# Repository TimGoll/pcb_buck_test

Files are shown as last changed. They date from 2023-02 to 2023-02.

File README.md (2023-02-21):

# Buck Test PCB

To get an understanding of different buck ICs and their drawbacks and benefits I designed this PCB. While all of them worked, some performed better than others. To verify my first impressions while initial testing I benchmarked the ICs over different voltages and currents.

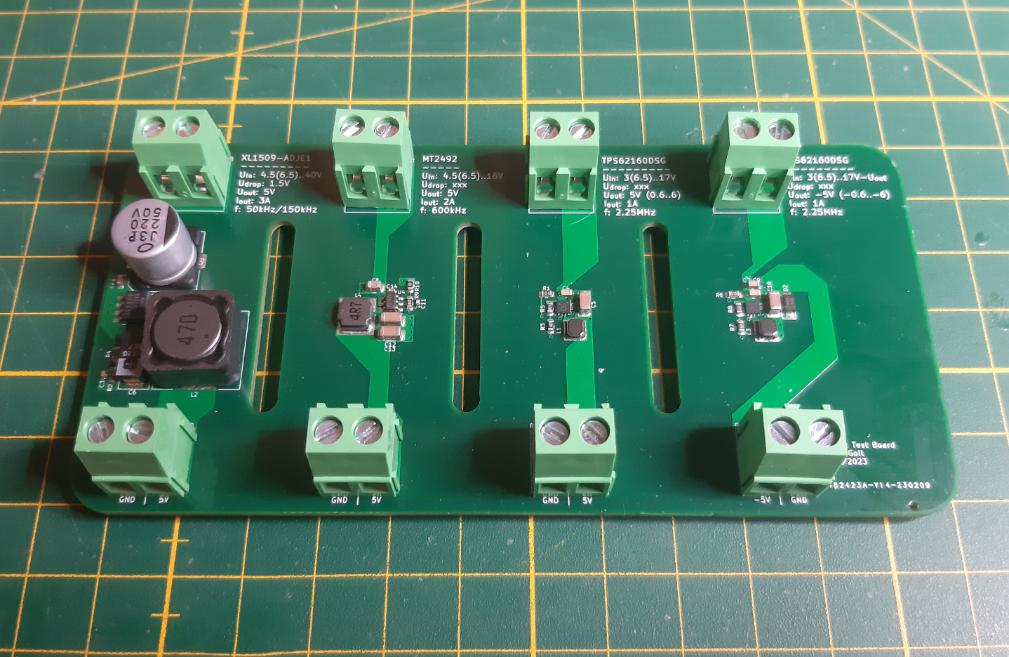
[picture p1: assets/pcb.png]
The testing PCB

_(the four different buck circuits that I tested)_

## ICs I tested

- XL1509-ADJE1 [[datasheet]](https://components.ubitap.com/datasheet/XL1509.pdf)
  - input voltage range: `4.5..40V`
  - output voltage: `1.23..37V` (fixed versions available too)
  - output current: `2A`
  - switching frequency: `50kHz/150kHz`
- MT2492 [[datasheet]](https://datasheet.lcsc.com/lcsc/1810262207_XI-AN-Aerosemi-Tech-MT2492_C89358.pdf)
  - input voltage range: `4.5..16V`
  - output voltage: `0.8..15V`
  - output current: `2A`
  - switching frequency: `600kHz`
- TPS62160DSG [[datasheet]](https://www.ti.com/lit/ds/symlink/tps62162.pdf?ts=1676897881217)
  - input voltage range: `3..17V`
  - output voltage: `0.9..6V` (fixed versions available too)
  - output current: `1A`
  - switching frequency: `2.25MHz`
  - can be used to create negative voltage

## Testing Results

### XL1509-ADJE1

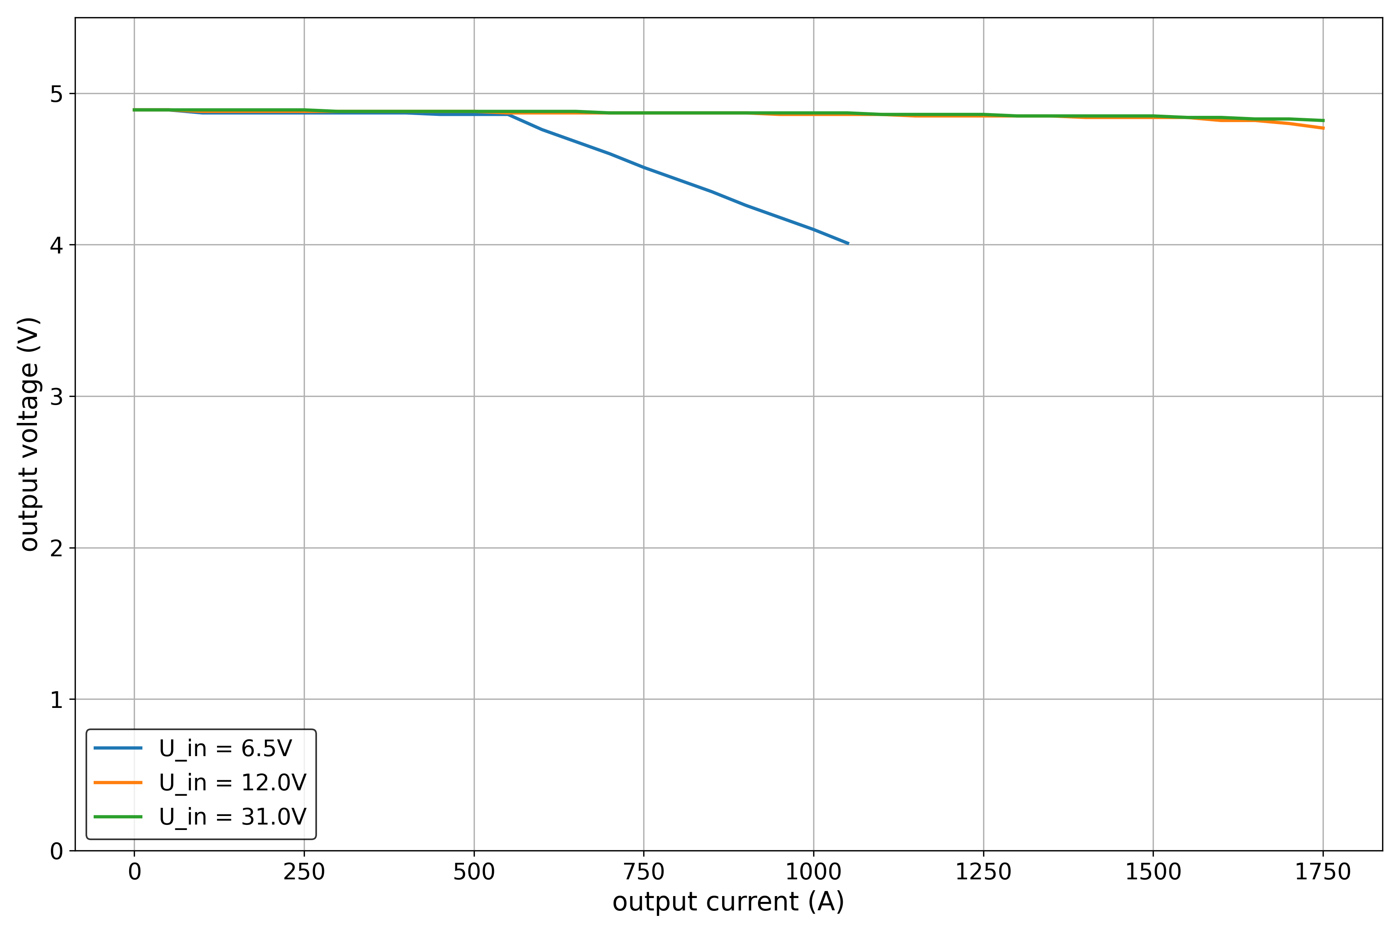
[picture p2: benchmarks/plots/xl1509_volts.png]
XL1509-ADJE1 voltage range

_(output voltage vs different output currents)_

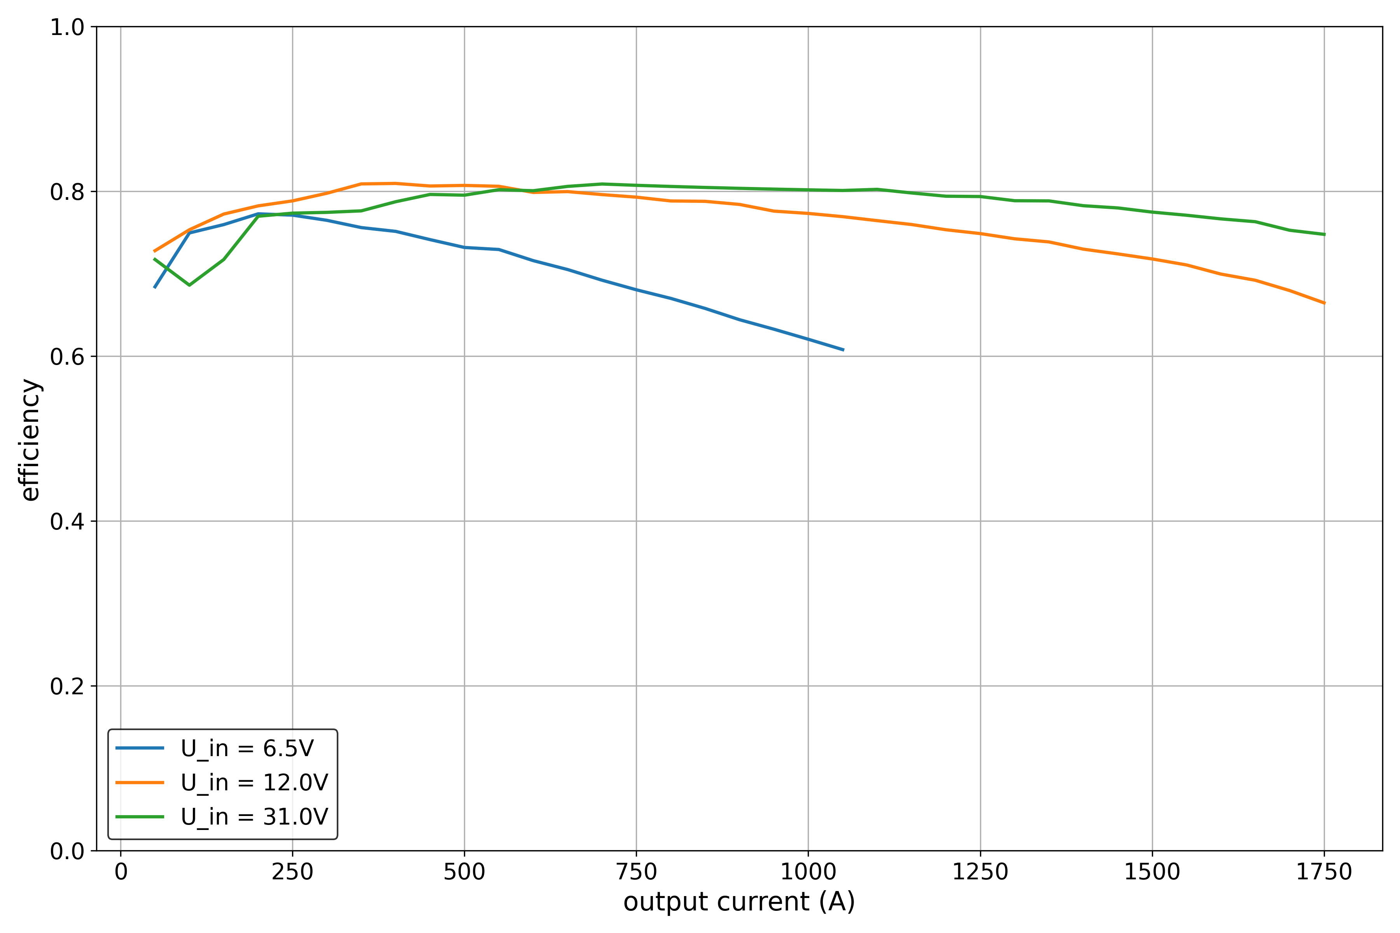
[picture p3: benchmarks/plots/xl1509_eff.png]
XL1509-ADJE1 efficiency range

_(efficiency vs different output currents)_

While this IC is very cheap and has a wide range of input voltages, everything else about it isn't worth it. The low switching frequency is the reason for the huge passive components that have to be added around this IC. This negates the benefit of its price since the required components are rather expensive.

Moreover this IC really struggled with thermals. I had to stop the tests at `1750mA` due to the output becoming instable because the IC overheated.

### MT2492

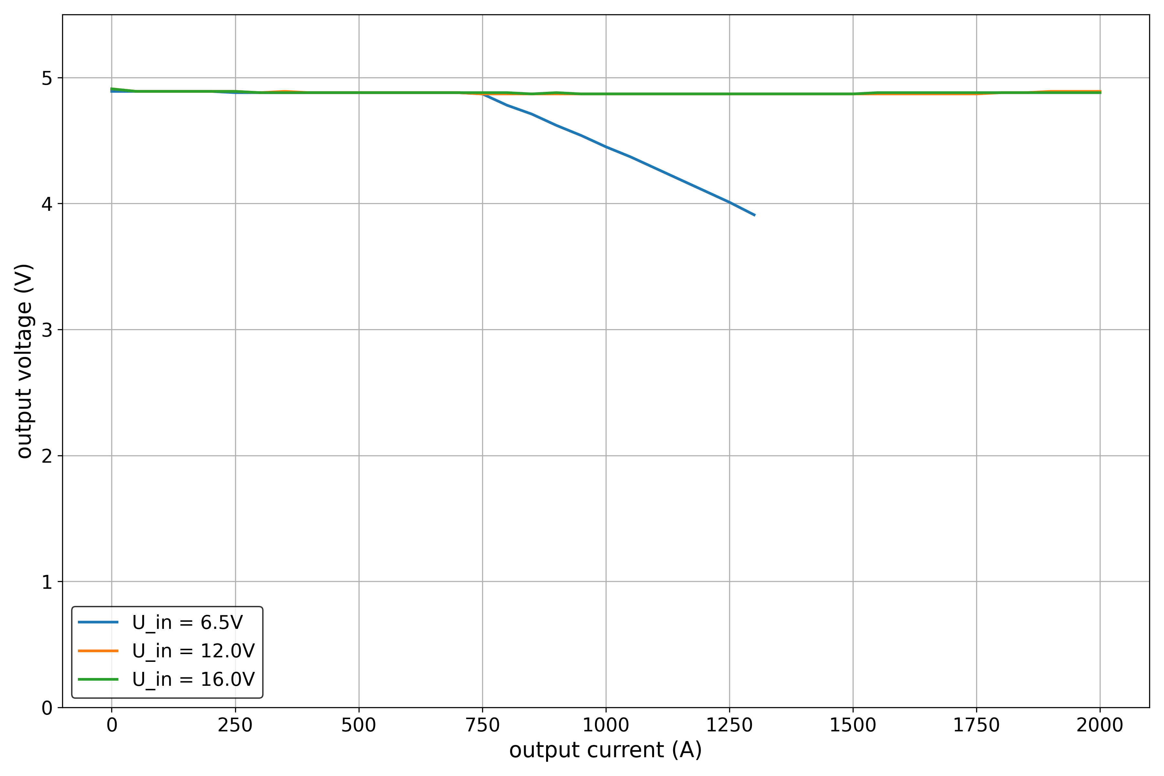
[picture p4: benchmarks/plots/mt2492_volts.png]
MT2492 voltage range

_(output voltage vs different output currents)_

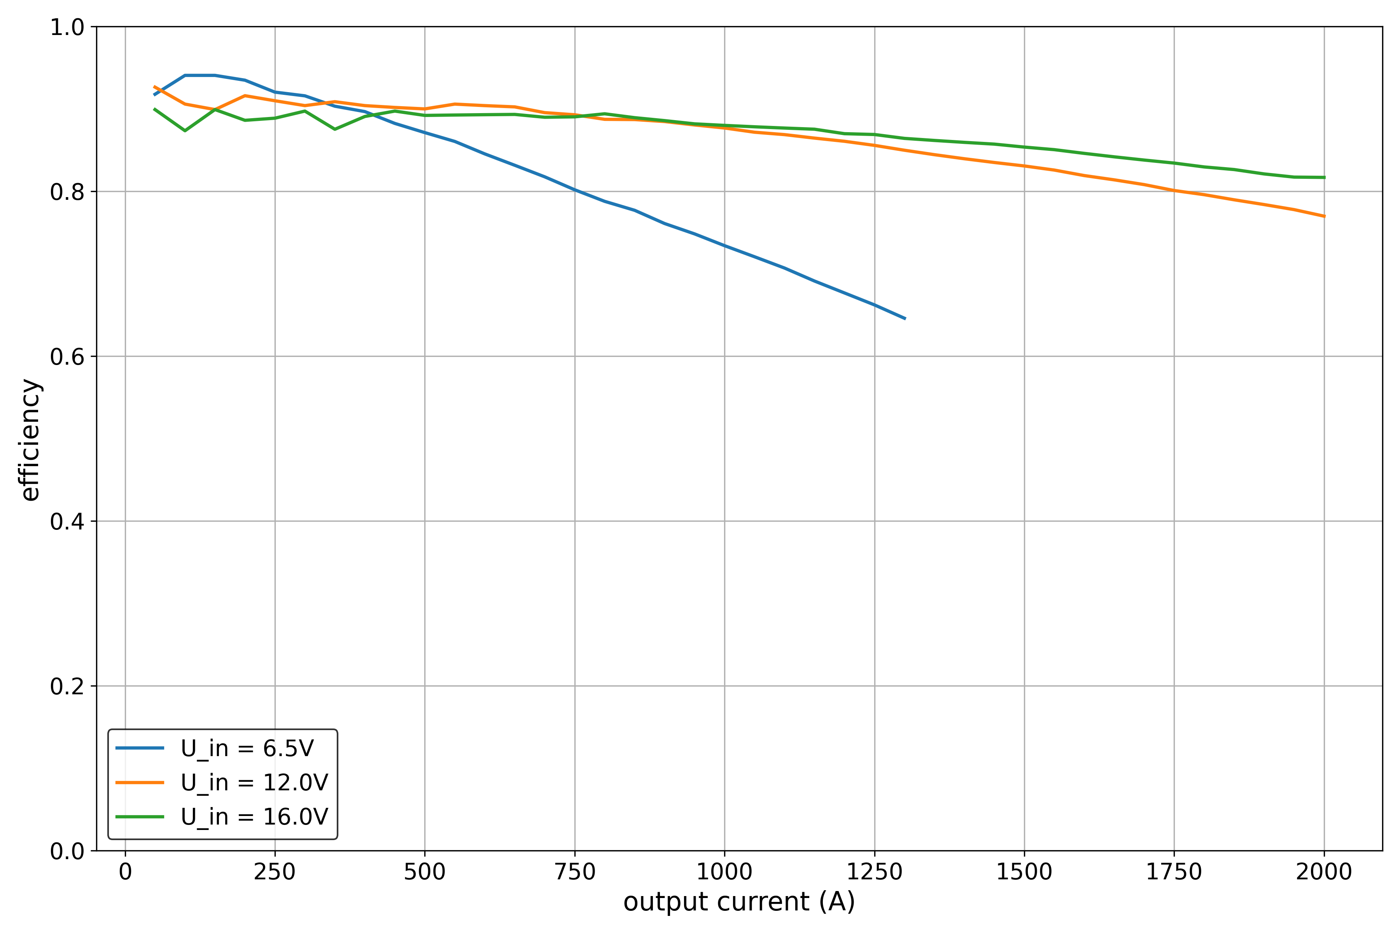
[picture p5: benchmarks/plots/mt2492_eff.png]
MT2492 efficiency range

_(efficiency vs different output currents)_

The MT2492 is a cheap and less capable copy of the [MP2492](https://www.monolithicpower.com/en/mp2492.html) by MPS. It comes in a small package that combined with the smaller passive components needs very little space on the PCB.

Its efficiency is rather good and the output voltage is stable. Even over the time of multiple minutes the IC did not overheat when `2A` were pulled.

All in all this is a good IC when more than `1A` of continuous current is needed.

### TPS62160DSG

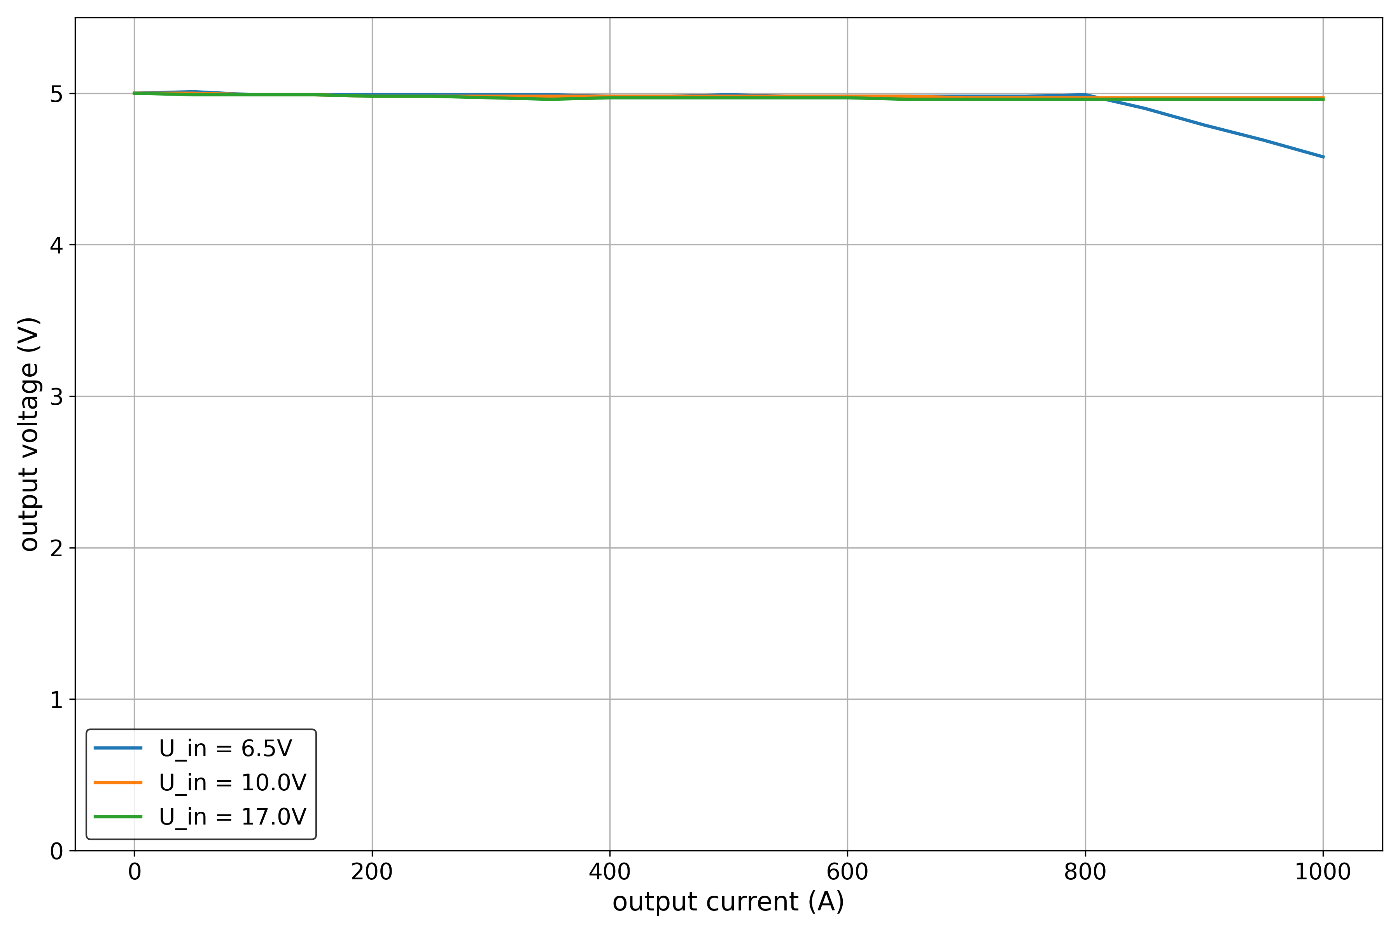
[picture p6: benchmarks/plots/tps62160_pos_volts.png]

_(output voltage vs different output currents)_

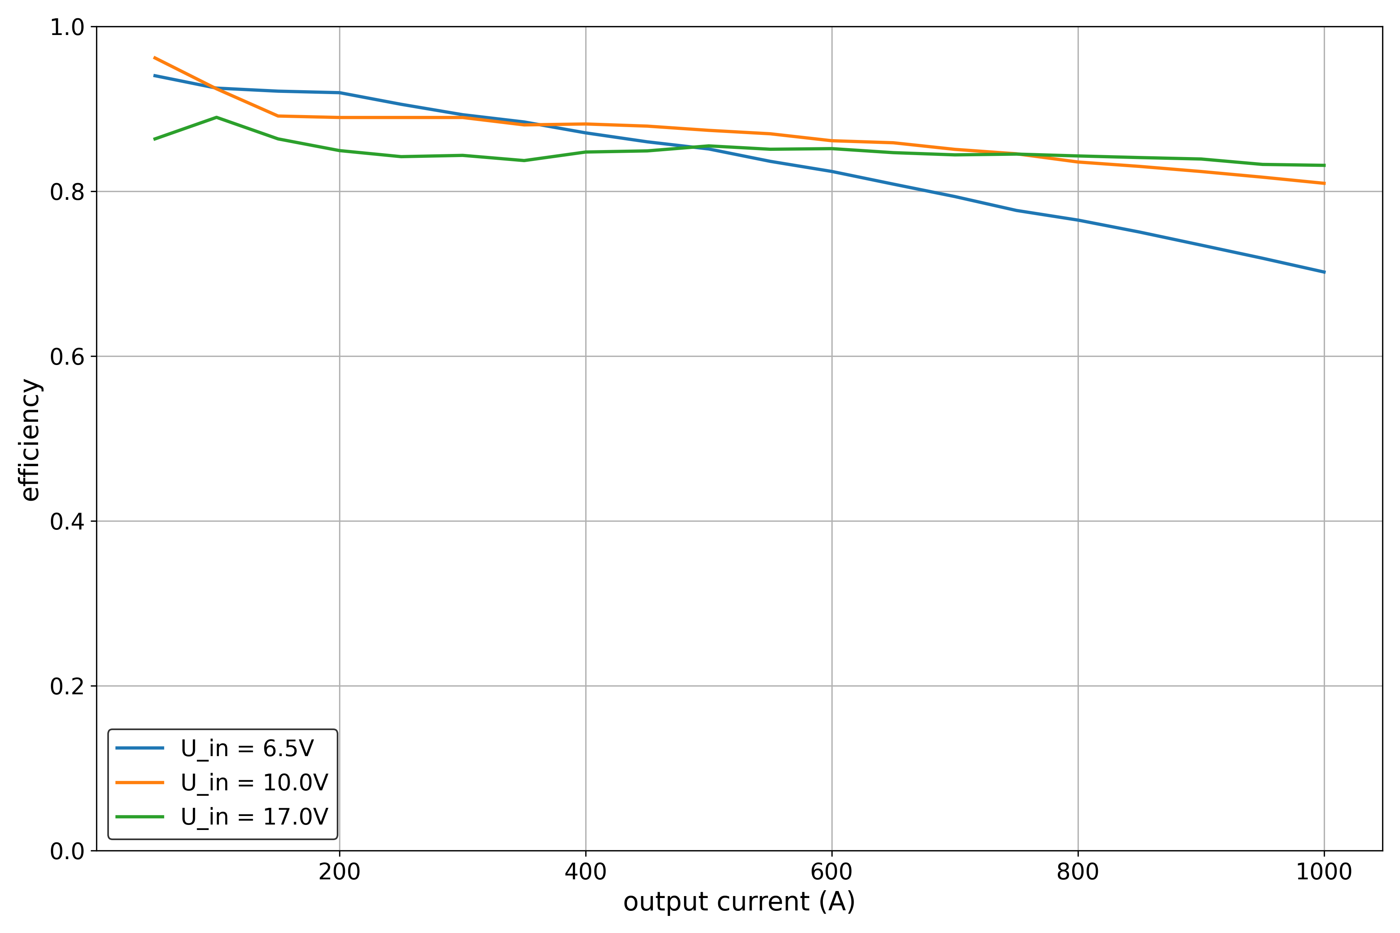
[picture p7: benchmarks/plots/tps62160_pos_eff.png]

_(efficiency vs different output currents)_

This IC made by TI is the smalles of them all. Paired with its high switching frequency the overall footprint of the circuit is really small. The output voltage is very stable, even for small drops and rather high currents. The efficiency is very good as well.

This is the best of the bunch, even though it is a bit more expensive. The most impressive thing is that it did not overheat, even though my thermal design for this circuit was very bad.

### TPS62160DSG (Inverted)

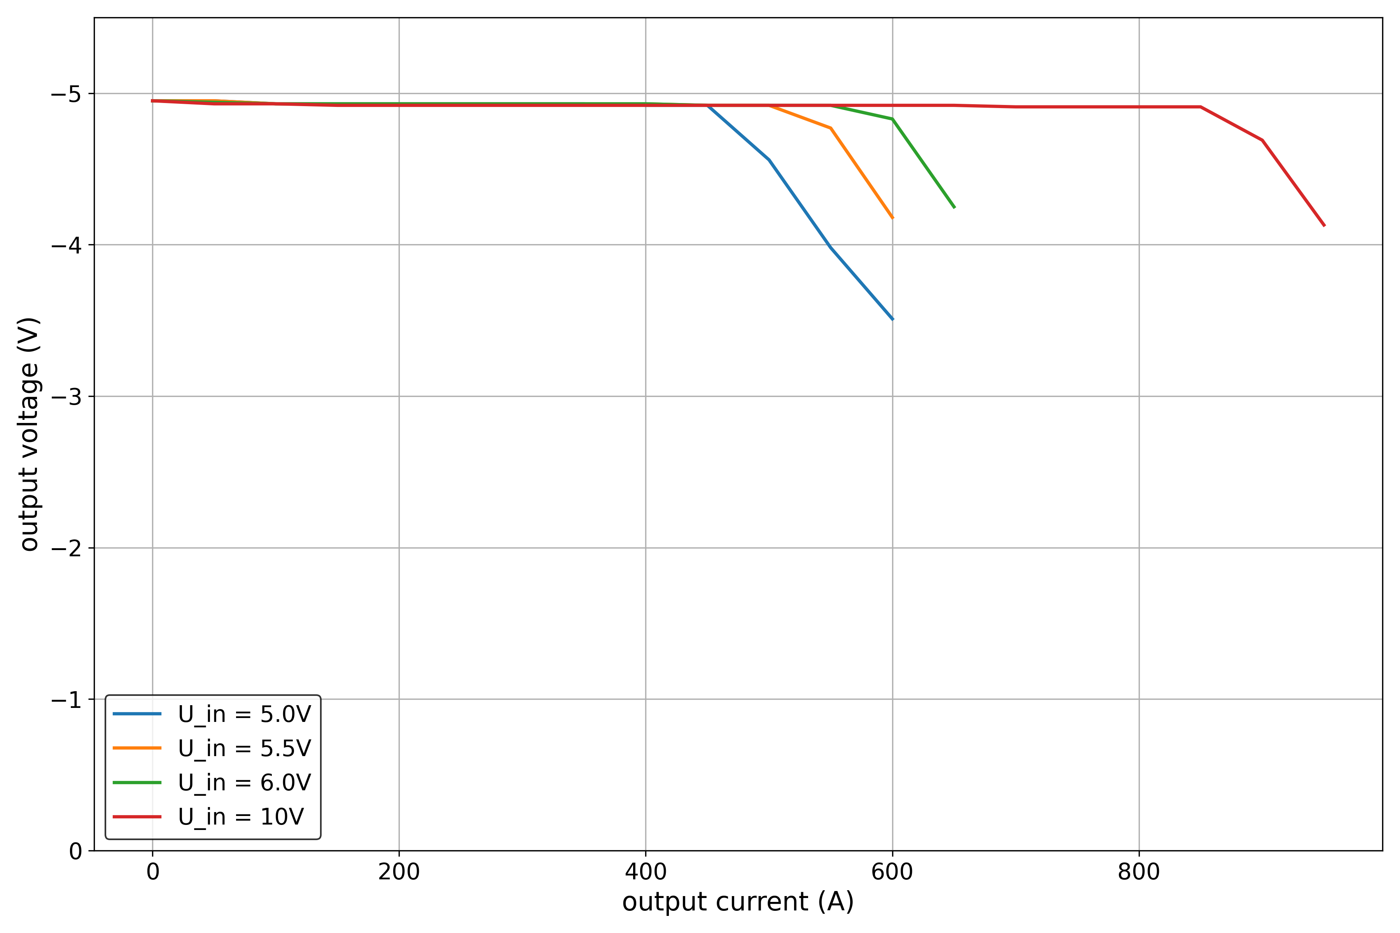
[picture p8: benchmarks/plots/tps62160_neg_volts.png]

_(output voltage vs different output currents)_

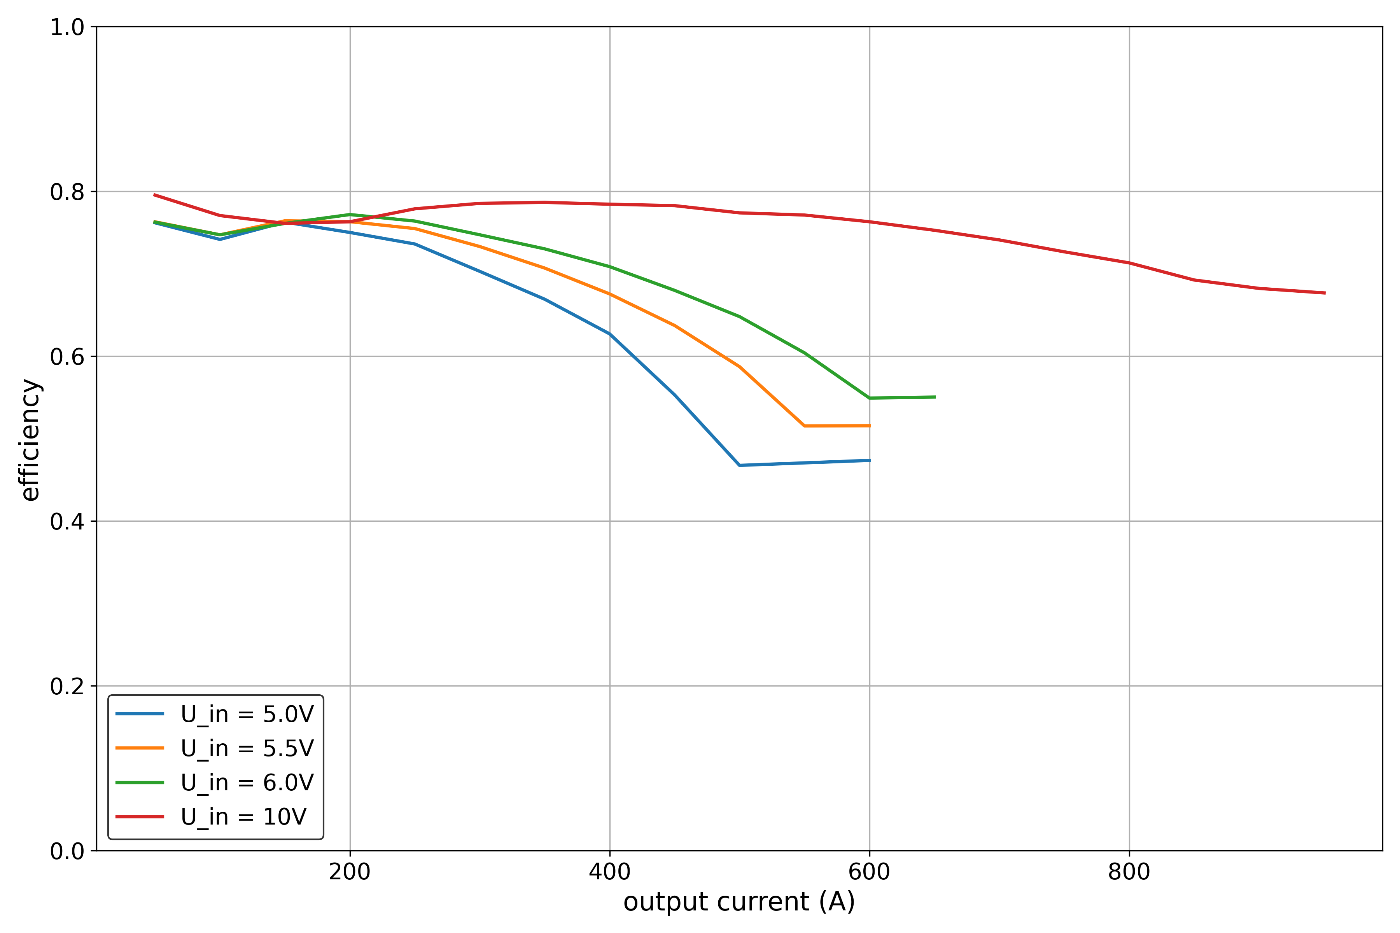
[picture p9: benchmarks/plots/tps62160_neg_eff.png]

_(efficiency vs different output currents)_

The same IC from the previous test was used again, but in a special configuration. With the addition of a few further passive components this IC can be used as an inverted power supply. While the input voltage range is decreased that way, the overall performance is still great.

One thing to highlight that it is possible to get stable `-5V` from a `5V` source for up to `450mA` of continous current. This makes this IC great for the use in OpAmp circuits where a negative rail is needed.

A minor drawback is that the efficiency is greatly reduced.

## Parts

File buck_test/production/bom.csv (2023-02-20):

Designator | Footprint | Quantity | Value | LCSC Part #
C1 | 0603 | 1 | 1u | C15849
C10 | 1206 | 1 | 22u 10V | C5672
C11 | 0402 | 1 | 22p | C1555
C12 | 1206 | 1 | 22u 10V | C5672
C13 | 1206 | 1 | 22u 10V | C5672
C14 | 0402 | 1 | 22n | C1532
C2 | CP_Elec_10x10 | 1 | 220u 50V | C125977
C3 | 0402 | 1 | 3n3 | C26404
C4 | 0603 | 1 | 10u 25V | C96446
C5 | 1206 | 1 | 22u 10V | C5672
C6 | CP_EIA-7343-31_Kemet-D | 1 | 220u 10V 25mR | C147767
C7 | 0603 | 1 | 10u 25V | C96446
C8 | 0805 | 1 | 22u 25V | C45783
C9 | 0603 | 1 | 10u 25V | C96446
D1, D2 | D_SOD-123 | 2 | DSK34 | C41029
J1, J2, J3, J4, J5, J6, J7, J8 | TerminalBlock_Phoenix_MKDS-1,5-2-5.08_1x02_P5.08mm_Horizontal | 8 | Conn_01x02 | C8465
L1, L3 | L_Wuerth_MAPI-3015 | 2 | 2u2 1..3A | C436631
L2 | L_12x12mm_H8mm | 1 | 47u 3A | C2983069
L4 | L_Wuerth_WE-PD2-Typ-MS | 1 | 4u7 2A | C354596
R1 | 0603 | 1 | 100k | C25803
R10 | 0603 | 1 | 15k | C22809
R2 | 0603 | 1 | 3k | C4211
R3 | 0603 | 1 | 680k | C25822
R4 | 0603 | 1 | 1k | C21190
R5 | 0603 | 1 | 130k | C22795
R6 | 0603 | 1 | 100k | C25803
R7 | 0603 | 1 | 680k | C25822
R8 | 0603 | 1 | 130k | C22795
R9 | 0603 | 1 | 110k | C25805
U1 | SOIC-8_3.9x4.9mm_P1.27mm | 1 | XL1509-ADJE1 | C2681227
U2, U3 | WSON-8-1EP_2x2mm_P0.5mm_EP0.9x1.6mm_ThermalVias | 2 | TPS62160DSG | C324077
U4 | SOT-23-6 | 1 | MT2492 | C89358

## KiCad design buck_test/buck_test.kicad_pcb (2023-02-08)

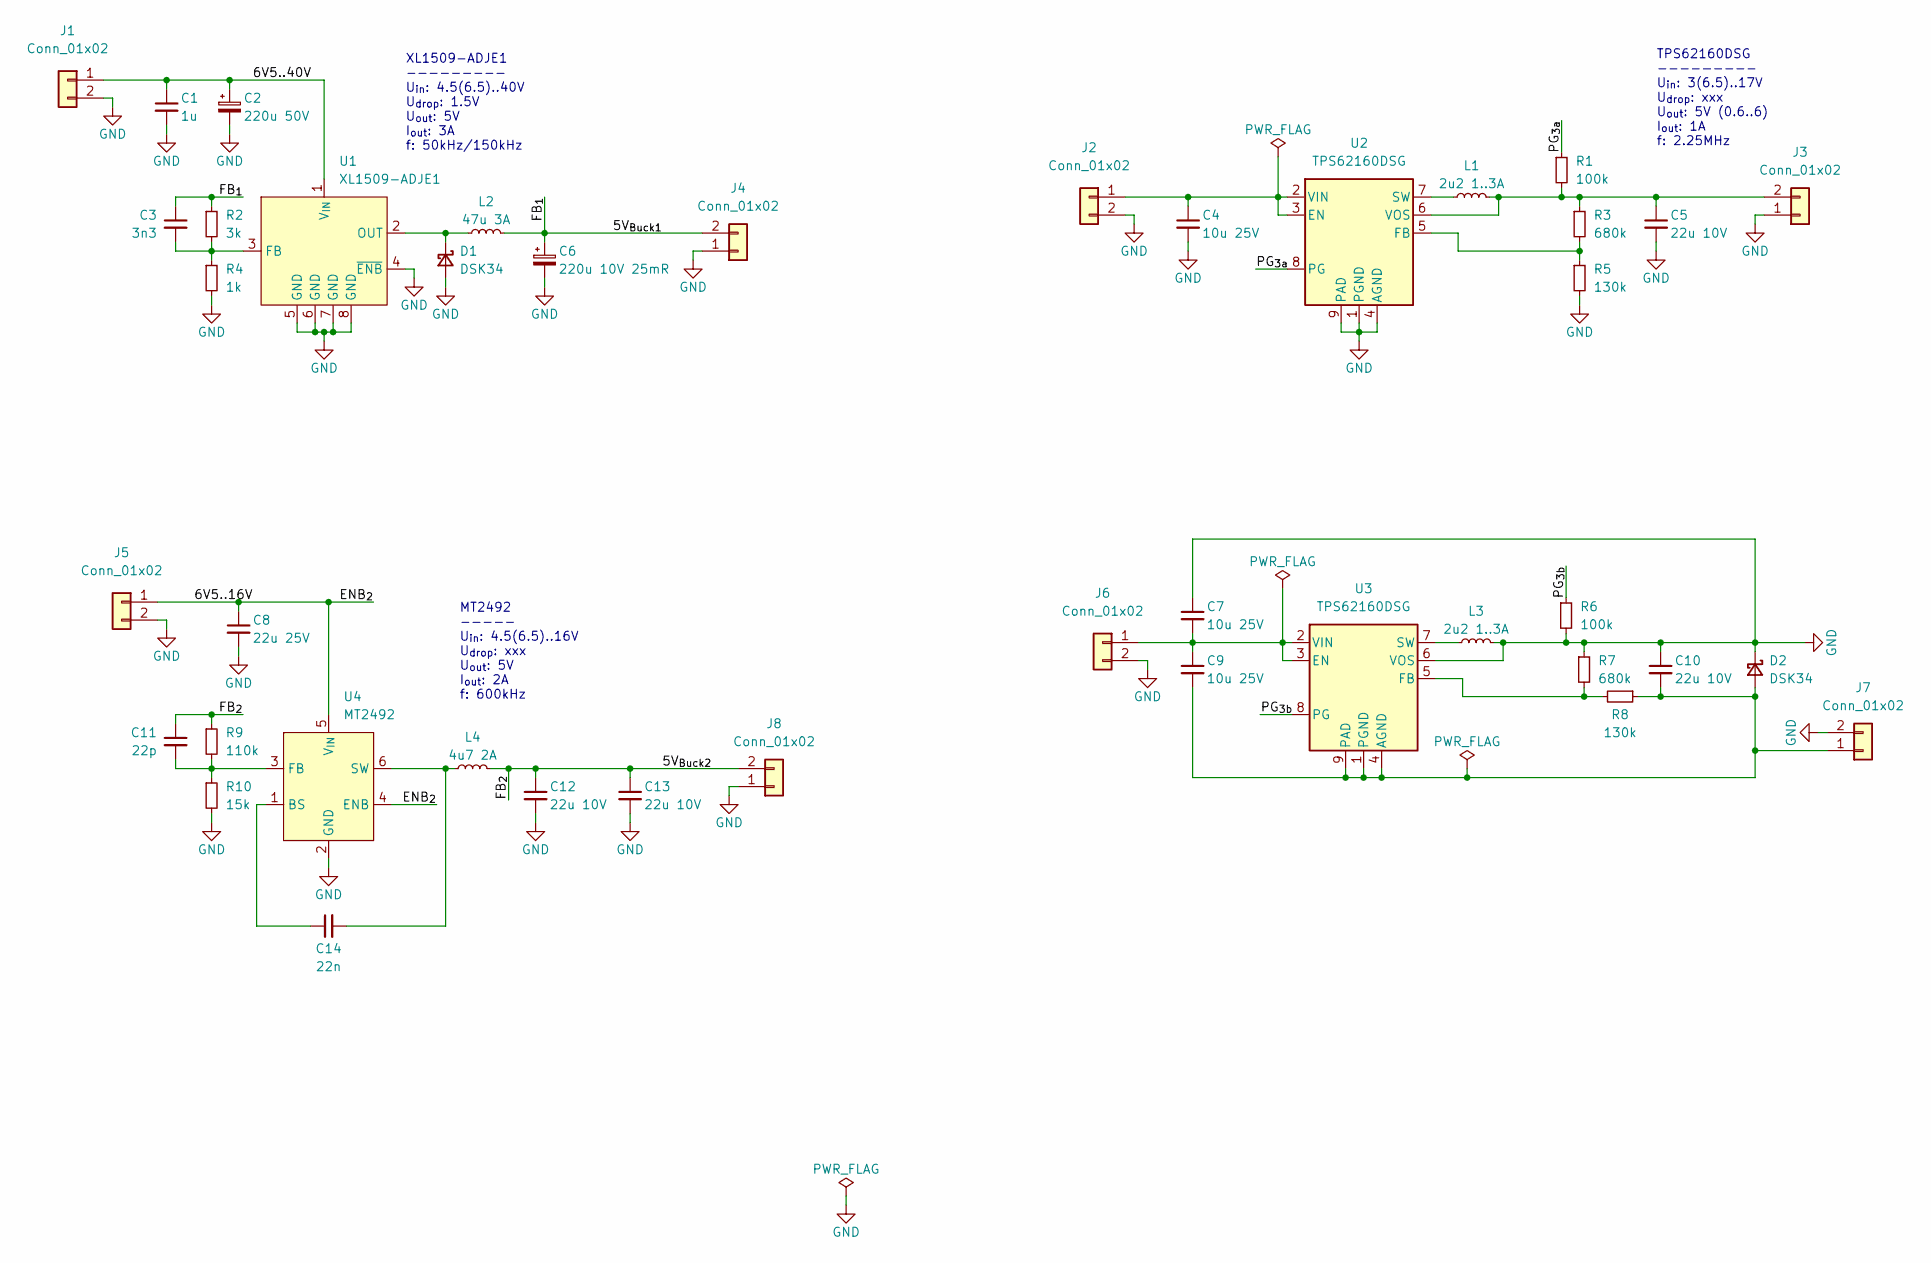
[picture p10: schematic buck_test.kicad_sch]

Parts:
C1: 1u; C_0603_1608Metric; LCSC Part # C15849
C2: 220u 50V; CP_Elec_10x10; LCSC Part # C125977
C3: 3n3; C_0402_1005Metric; LCSC Part # C26404
C4, C7, C9: 10u 25V; C_0603_1608Metric; LCSC Part # C96446
C5, C10, C12, C13: 22u 10V; C_1206_3216Metric; LCSC Part # C5672
C6: 220u 10V 25mR; CP_EIA-7343-31_Kemet-D; LCSC Part # C147767
C8: 22u 25V; C_0805_2012Metric; LCSC Part # C45783
C11: 22p; C_0402_1005Metric; LCSC Part # C1555
C14: 22n; C_0402_1005Metric; LCSC Part # C1532
D1, D2: DSK34; D_SOD-123; LCSC Part # C41029
J1, J2, J3, J4, J5, J6, J7, J8: Conn_01x02; TerminalBlock_Phoenix_MKDS-1,5-2-5.08_1x02_P5.08mm_Horizont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; LCSC Part # C8465
L1, L3: 2u2 1..3A; L_Wuerth_MAPI-3015; LCSC Part # C436631
L2: 47u 3A; L_12x12mm_H8mm; LCSC Part # C2983069
L4: 4u7 2A; L_Wuerth_WE-PD2-Typ-MS; LCSC Part # C354596
R1, R6: 100k; R_0603_1608Metric; LCSC Part # C25803
R2: 3k; R_0603_1608Metric; LCSC Part # C4211
R3, R7: 680k; R_0603_1608Metric; LCSC Part # C25822
R4: 1k; R_0603_1608Metric; LCSC Part # C21190
R5, R8: 130k; R_0603_1608Metric; LCSC Part # C22795
R9: 110k; R_0603_1608Metric; LCSC Part # C25805
R10: 15k; R_0603_1608Metric; LCSC Part # C22809
U1: XL1509-ADJE1; SOIC-8_3.9x4.9mm_P1.27mm; LCSC Part # C2681227
U2, U3: TPS62160DSG; WSON-8-1EP_2x2mm_P0.5mm_EP0.9x1.6mm_ThermalVias; LCSC Part # C324077
U4: MT2492; SOT-23-6; LCSC Part # C89358

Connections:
/5V_{Buck1}: C3.1, C6.1, J4.2, L2.2, R2.1
/5V_{Buck2}: C11.1, C12.1, C13.1, J8.2, L4.2, R9.1
/6V5..16V: C8.1, J5.1, U4.4 (ENB), U4.5 (V_{IN})
/6V5..40V: C1.1, C2.1, J1.1, U1.1 (V_{IN})
/PG_{3a}: R1.1, U2.8 (PG)
/PG_{3b}: R6.1, U3.8 (PG)
GND: C1.2, C2.2, C4.2, C5.2, C6.2, C7.1, C8.2, C10.1, C12.2, C13.2, D1.2 (A), D2.1 (K), J1.2, J2.2, J3.1, J4.1, J5.2, J6.2, J7.2, J8.1, L3.2, R4.2, R5.2, R6.2, R7.1, R10.2, U1.4 (~ENB), U1.5 (GND), U1.6 (GND), U1.7 (GND), U1.8 (GND), U2.1 (PGND), U2.4 (AGND), U2.9 (PAD), U3.6 (VOS), U4.2 (GND)
unnamed: C3.2, R2.2, R4.1, U1.3 (FB)
unnamed: C4.1, J2.1, U2.2 (VIN), U2.3 (EN)
unnamed: C5.1, J3.2, L1.2, R1.2, R3.1, U2.6 (VOS)
unnamed: C7.2, C9.1, J6.1, U3.2 (VIN), U3.3 (EN)
unnamed: C9.2, C10.2, D2.2 (A), J7.1, R8.1, U3.1 (PGND), U3.4 (AGND), U3.9 (PAD)
unnamed: C11.2, R9.2, R10.1, U4.3 (FB)
unnamed: C14.1, U4.1 (BS)
unnamed: C14.2, L4.1, U4.6 (SW)
unnamed: D1.1 (K), L2.1, U1.2 (OUT)
unnamed: L1.1, U2.7 (SW)
unnamed: L3.1, U3.7 (SW)
unnamed: R3.2, R5.1, U2.5 (FB)
unnamed: R7.2, R8.2, U3.5 (FB)

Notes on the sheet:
XL1509-ADJE1 --------- U_{in}: 4.5(6.5)..40V U_{drop}: 1.5V U_{out}: 5V I_{out}: 3A f: 50kHz/150kHz
TPS62160DSG --------- U_{in}: 3(6.5)..17V U_{drop}: xxx U_{out}: 5V (0.6..6) I_{out}: 1A f: 2.25MHz
MT2492 ----- U_{in}: 4.5(6.5)..16V U_{drop}: xxx U_{out}: 5V I_{out}: 2A f: 600kHz

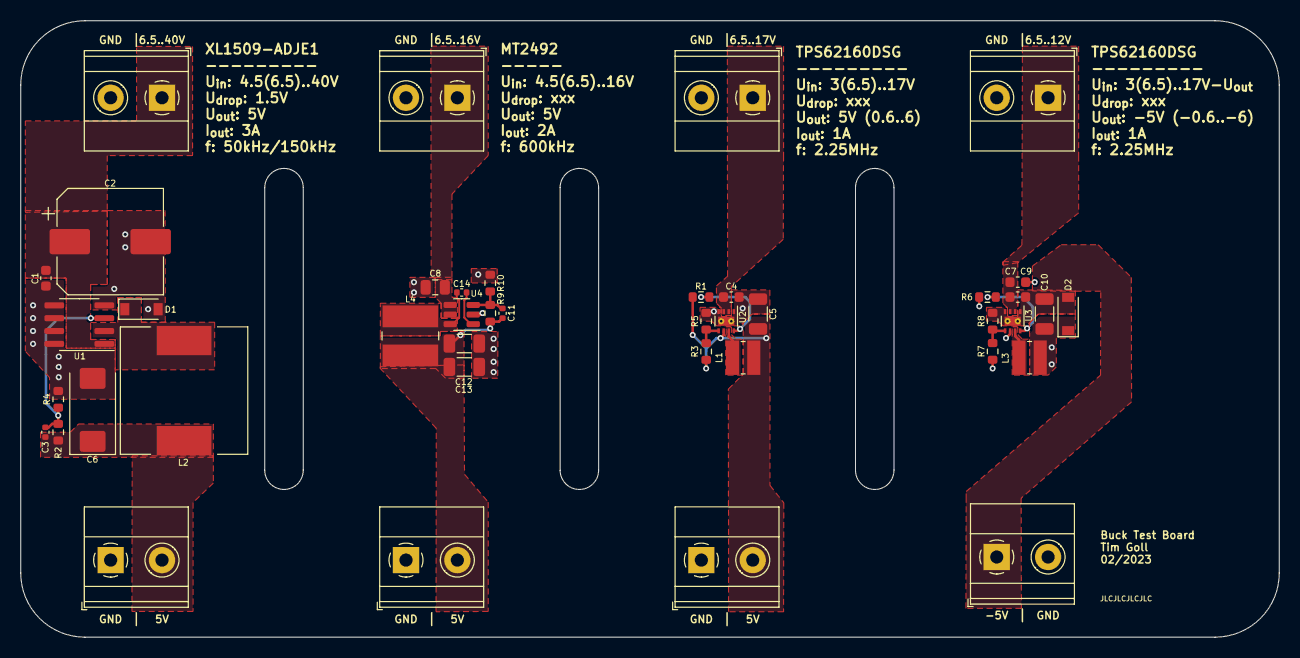
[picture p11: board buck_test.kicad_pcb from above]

Board: 4 copper layers, 124.5 x 61.0 mm, 42 parts (0 on the bottom side), 20 nets.

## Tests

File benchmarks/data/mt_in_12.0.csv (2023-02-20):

I_out | U_out | I_in | U_in
0 | 4.91 | 0 | 12.00
50 | 4.89 | 22 | 12.00
100 | 4.89 | 45 | 12.00
150 | 4.89 | 68 | 12.00
200 | 4.89 | 89 | 12.00
250 | 4.89 | 112 | 12.00
300 | 4.88 | 135 | 12.00
350 | 4.89 | 157 | 12.00
400 | 4.88 | 180 | 12.00
450 | 4.88 | 203 | 12.00
500 | 4.88 | 226 | 12.00
550 | 4.88 | 247 | 12.00
600 | 4.88 | 270 | 12.00
650 | 4.88 | 293 | 12.00
700 | 4.88 | 318 | 12.00
750 | 4.87 | 341 | 12.00
800 | 4.87 | 366 | 12.00
850 | 4.87 | 389 | 12.00
900 | 4.87 | 413 | 12.00
950 | 4.87 | 438 | 12.00
1000 | 4.87 | 463 | 12.00
1050 | 4.87 | 489 | 12.00
1100 | 4.87 | 514 | 12.00
1150 | 4.87 | 540 | 12.00
1200 | 4.87 | 566 | 12.00
1250 | 4.87 | 593 | 12.00
1300 | 4.87 | 621 | 12.00
1350 | 4.87 | 649 | 12.00
1400 | 4.87 | 677 | 12.00
1450 | 4.87 | 705 | 12.00
1500 | 4.87 | 733 | 12.00
1550 | 4.87 | 762 | 12.00
1600 | 4.87 | 793 | 12.00
1650 | 4.87 | 823 | 12.00
1700 | 4.87 | 854 | 12.00
1750 | 4.87 | 887 | 12.00
1800 | 4.88 | 920 | 12.00
1850 | 4.88 | 953 | 12.00
1900 | 4.89 | 988 | 12.00
1950 | 4.89 | 1022 | 12.00
2000 | 4.89 | 1059 | 12.00

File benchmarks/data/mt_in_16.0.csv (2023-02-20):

I_out | U_out | I_in | U_in
0 | 4.91 | 0 | 16.00
50 | 4.89 | 17 | 16.00
100 | 4.89 | 35 | 16.00
150 | 4.89 | 51 | 16.00
200 | 4.89 | 69 | 16.00
250 | 4.89 | 86 | 16.00
300 | 4.88 | 102 | 16.00
350 | 4.88 | 122 | 16.00
400 | 4.88 | 137 | 16.00
450 | 4.88 | 153 | 16.00
500 | 4.88 | 171 | 16.00
550 | 4.88 | 188 | 16.00
600 | 4.88 | 205 | 16.00
650 | 4.88 | 222 | 16.00
700 | 4.88 | 240 | 16.00
750 | 4.88 | 257 | 16.00
800 | 4.88 | 273 | 16.00
850 | 4.87 | 291 | 16.00
900 | 4.88 | 310 | 16.00
950 | 4.87 | 328 | 16.00
1000 | 4.87 | 346 | 16.00
1050 | 4.87 | 364 | 16.00
1100 | 4.87 | 382 | 16.00
1150 | 4.87 | 400 | 16.00
1200 | 4.87 | 420 | 16.00
1250 | 4.87 | 438 | 16.00
1300 | 4.87 | 458 | 16.00
1350 | 4.87 | 477 | 16.00
1400 | 4.87 | 496 | 16.00
1450 | 4.87 | 515 | 16.00
1500 | 4.87 | 535 | 16.00
1550 | 4.88 | 556 | 16.00
1600 | 4.88 | 577 | 16.00
1650 | 4.88 | 598 | 16.00
1700 | 4.88 | 619 | 16.00
1750 | 4.88 | 640 | 16.00
1800 | 4.88 | 662 | 16.00
1850 | 4.88 | 683 | 16.00
1900 | 4.88 | 706 | 16.00
1950 | 4.88 | 728 | 16.00
2000 | 4.88 | 747 | 16.00

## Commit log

2023-02-06 added schematic and BOM
    [buck_test.kicad_pcb, buck_test.kicad_sch]
2023-02-07 started PCB routing
    [buck_test.kicad_pcb]
2023-02-08 finished routing
    [buck_test.kicad_pcb, buck_test.kicad_sch]
2023-02-20 removed plots from ignore
    [bom.csv, designators.csv, mt_in_12.0.csv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]
2023-02-21 kicad 7 update
    [buck_test.kicad_sch]
